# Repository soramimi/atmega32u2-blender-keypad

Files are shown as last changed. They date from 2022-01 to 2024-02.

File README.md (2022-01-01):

# atmega32u2-blender-keypad

Customized keypad for modeling with Blender.

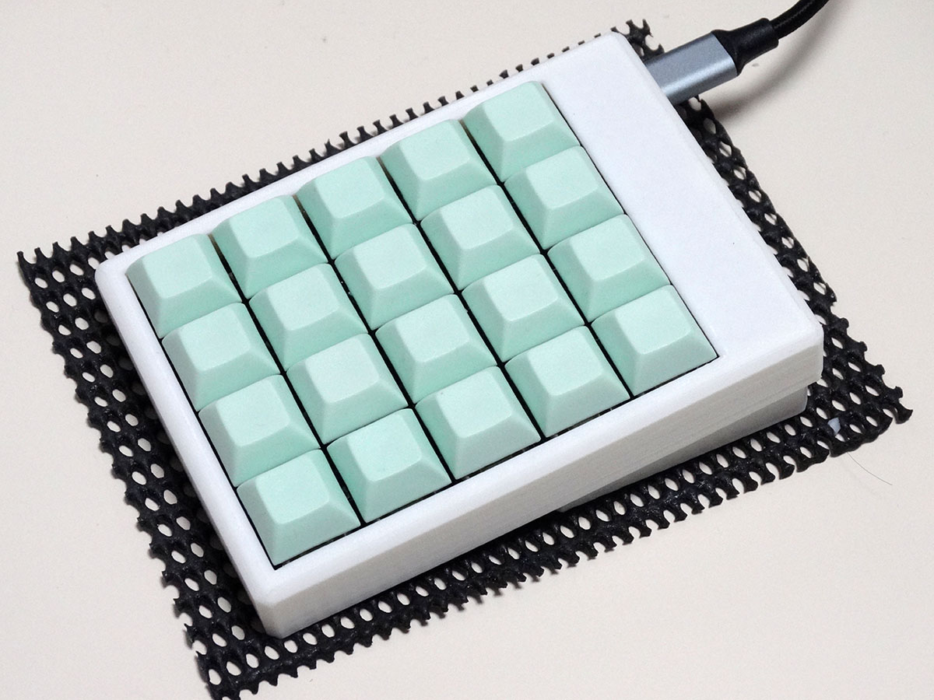
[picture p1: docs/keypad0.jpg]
Keypad

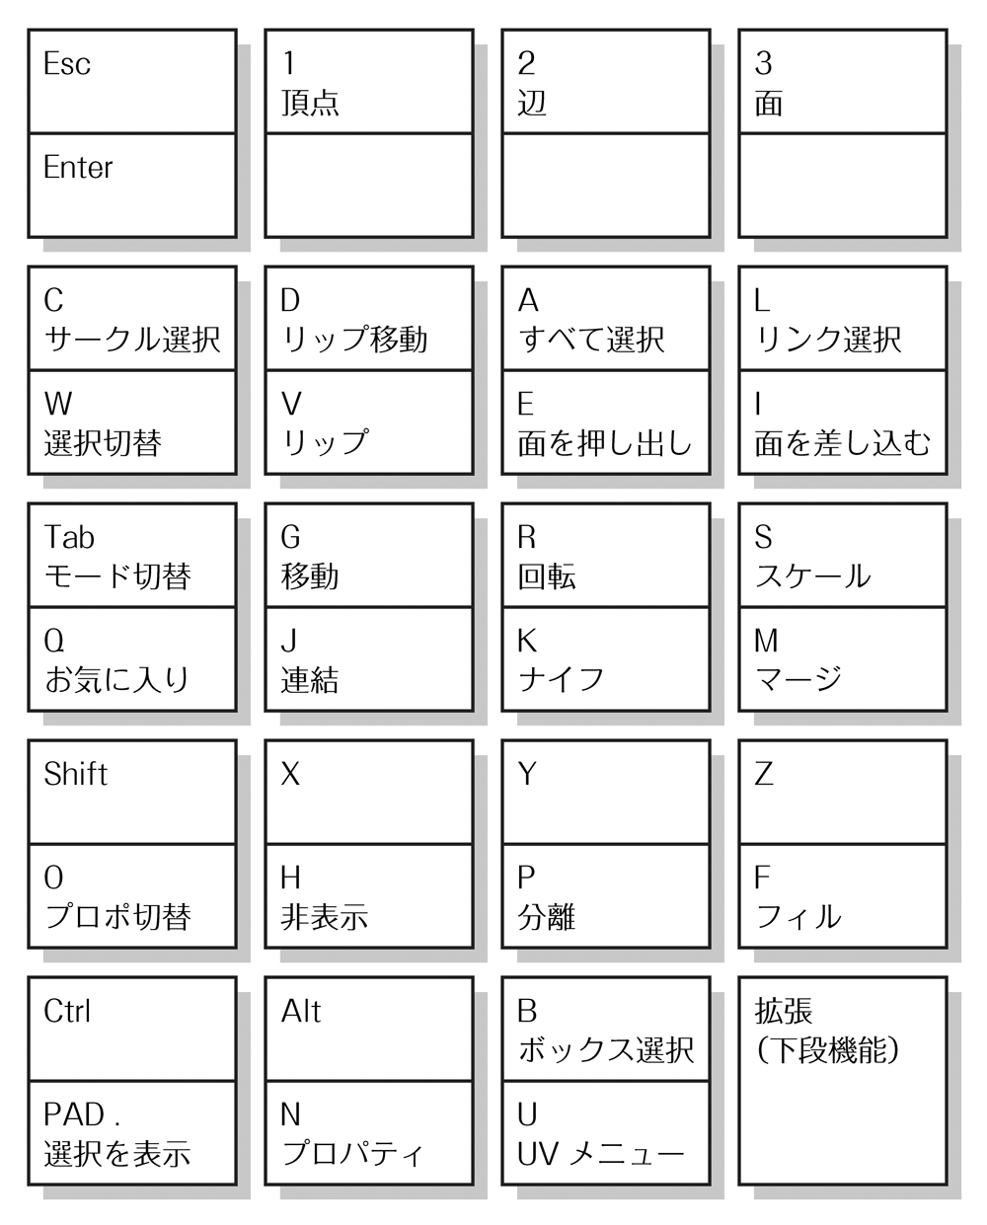
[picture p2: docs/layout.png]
Layout

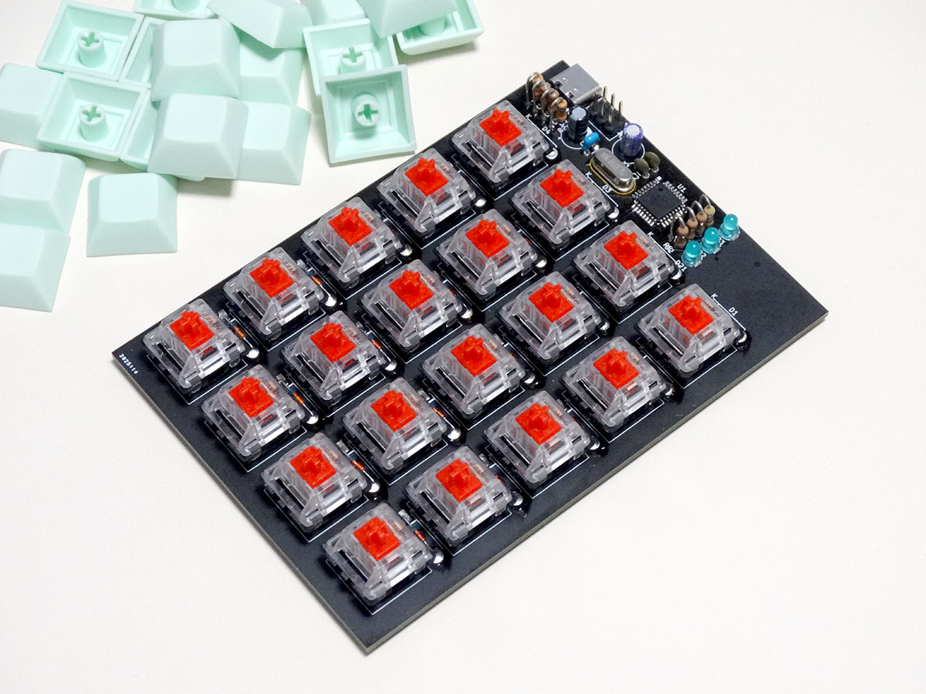
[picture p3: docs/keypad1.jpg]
PCB1

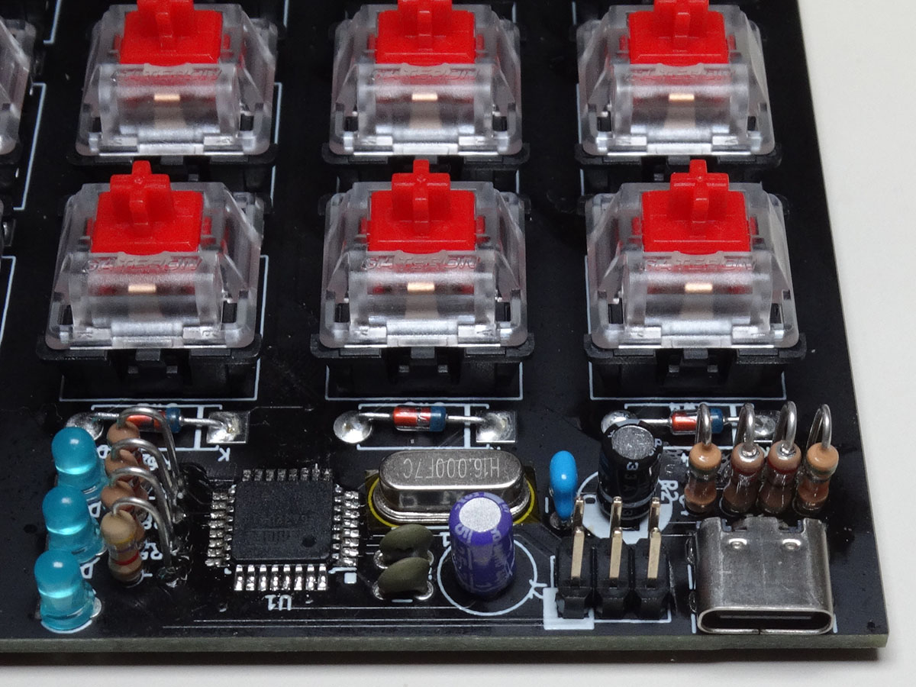
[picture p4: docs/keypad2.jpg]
PCB2


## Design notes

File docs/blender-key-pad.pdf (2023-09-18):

Esc

Enter

W
選択切替

G
移動

S
スケール

K
ナイフ

P
分離

H
非表示

N
サイドバー

J
連結

Q
お気に入り

F
フィル

D
リップ移動

I
面を差し込む

E
面を押し出し

Tab
モード切替

Shift+7
選択面を正面

5
投影法切替

O
プロポ切替

T
ツールバー

U
UV メニュー

M
マージ

R
回転

A
すべて選択

L
リンク選択

C
サークル選択

B
ボックス選択
Shift | X
Ctrl | Alt
選択をズーム

2ｽﾄﾛｰｸ

拡張
（下段機能）
Y | Z

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
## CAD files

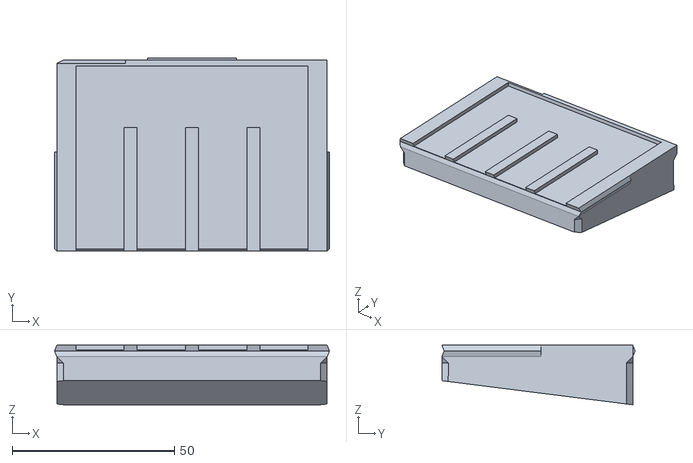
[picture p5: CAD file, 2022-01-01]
case/20keypad-c-bottom-a.stl
84.7 x 59.5 x 18.3

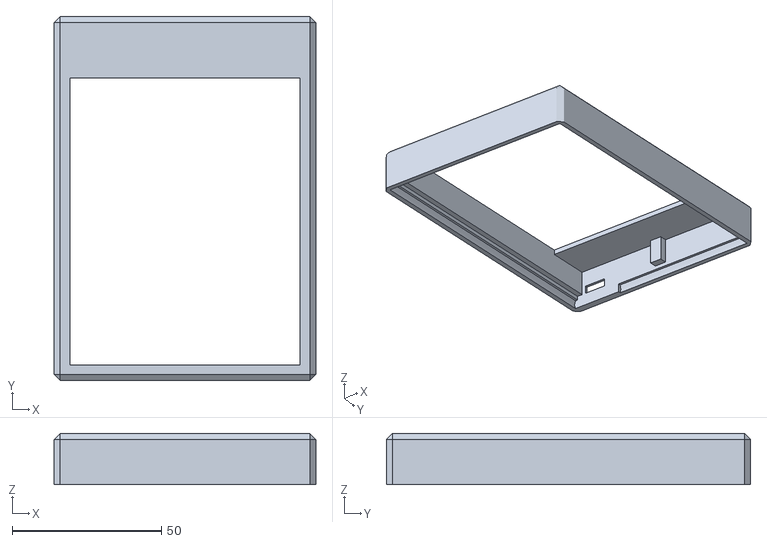
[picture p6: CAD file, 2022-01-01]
case/20keypad-c-cover.stl
87.7 x 122.0 x 17.1

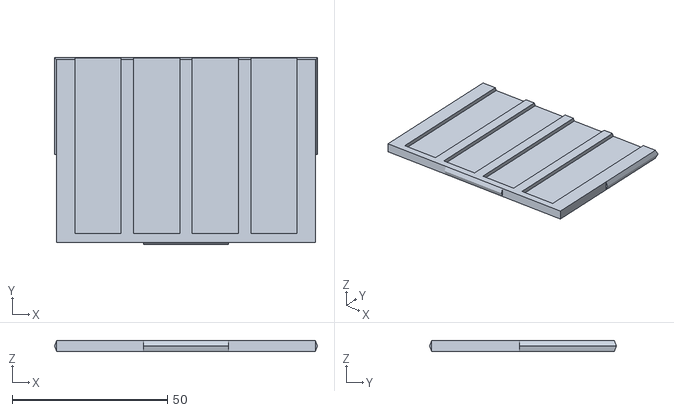
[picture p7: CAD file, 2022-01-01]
case/20keypad-c-bottom-b.stl
84.7 x 60.2 x 3.50

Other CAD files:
case/20keypad-c-bottom-a.blend
case/20keypad-c-bottom-b.blend
case/20keypad-c-cover.blend
case/20keypad-c.blend

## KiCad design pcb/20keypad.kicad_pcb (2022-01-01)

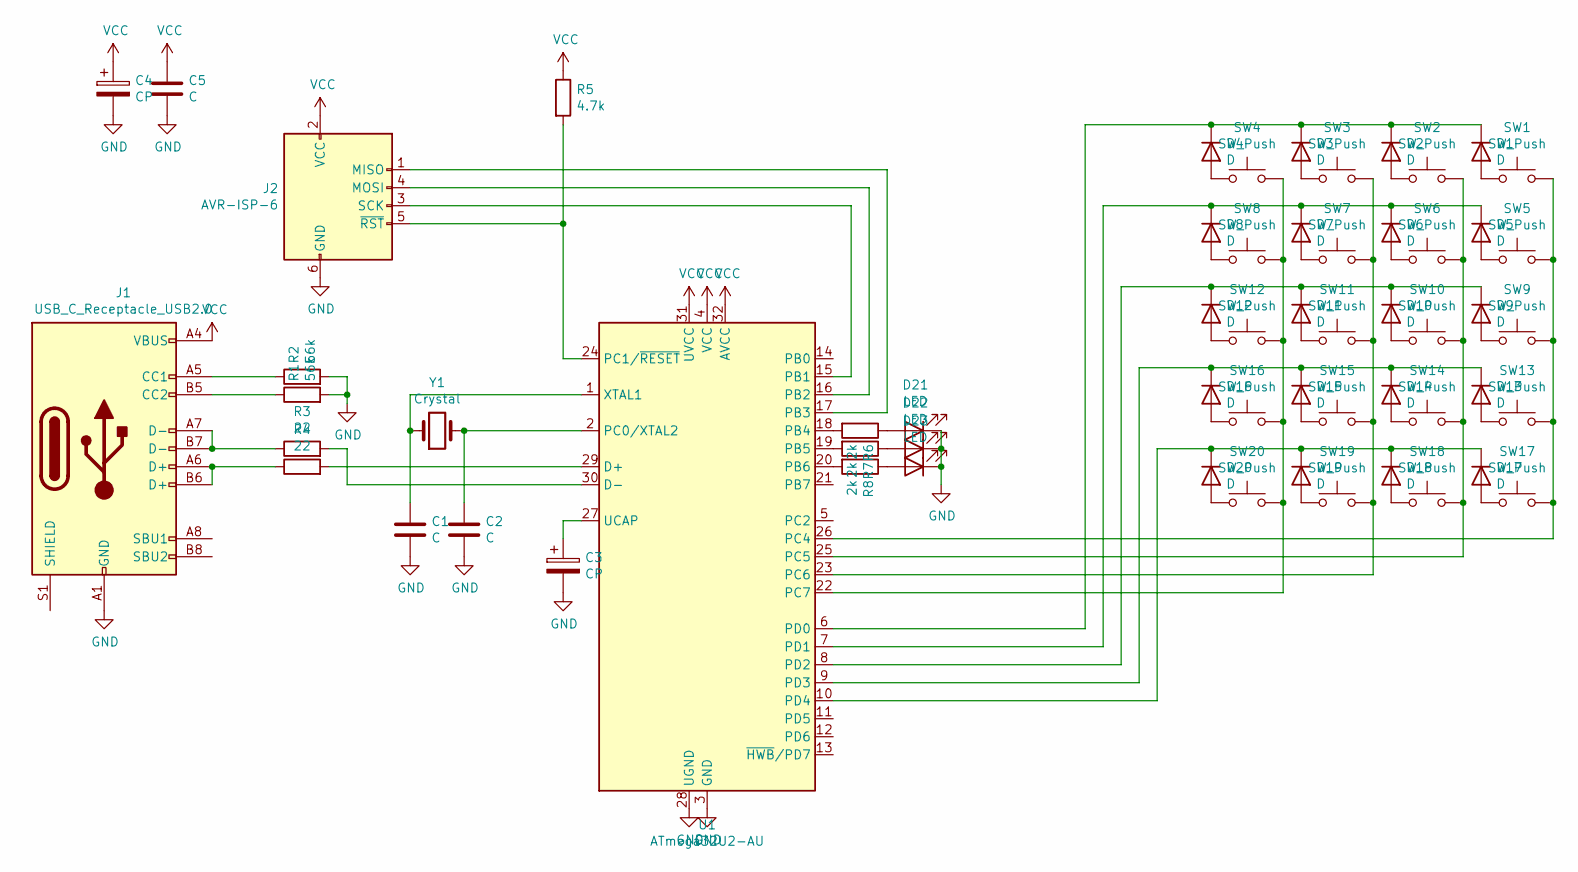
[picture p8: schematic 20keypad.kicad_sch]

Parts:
C1, C2, C5: C; C_Disc_D3.0mm_W1.6mm_P2.50mm
C3, C4: CP; CP_Radial_D6.3mm_P2.50mm
D1, D2, D3, D4, D5, D6, D7, D8, D9, D10, D11, D12, D13, D14, D15, D16, D17, D18, D19, D20: D; D_A-405_P7.62mm_Horizontal
D21, D22, D23: LED; LED_D3.0mm
J1: USB_C_Receptacle_USB2.0; USB_C_Receptacle_HRO_TYPE-C-31-M-12
J2: AVR-ISP-6; PinHeader_2x03_P2.54mm_Vertical
R1, R2: 56k; R_Axial_DIN0204_L3.6mm_D1.6mm_P2.54mm_Vertical
R3, R4: 22; R_Axial_DIN0204_L3.6mm_D1.6mm_P2.54mm_Vertical
R5: 4.7k; R_Axial_DIN0204_L3.6mm_D1.6mm_P2.54mm_Vertical
R6, R7, R8: 2k; R_Axial_DIN0204_L3.6mm_D1.6mm_P2.54mm_Vertical
SW1, SW2, SW3, SW4, SW5, SW6, SW7, SW8, SW9, SW10, SW11, SW12, SW13, SW14, SW15, SW16, SW17, SW18, SW19, SW20: SW_Push; SW_Cherry_MX_1.00u_PCB
U1: ATmega32U2-AU; TQFP-32_7x7mm_P0.8mm
Y1: Crystal; Crystal_HC49-U_Vertical

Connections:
GND: C1.2, C2.2, C3.2, C4.2, C5.2, D21.1 (K), D22.1 (K), D23.1 (K), J1.A1 (GND), J1.A12 (GND), J1.B1 (GND), J1.B12 (GND), J2.6 (GND), R1.2, R2.2, U1.3 (GND), U1.28 (UGND)
unnamed: C1.1, U1.1 (XTAL1), Y1.1
unnamed: C2.1, U1.2 (PC0/XTAL2), Y1.2
unnamed: C3.1, U1.27 (UCAP)
unnamed: D1.1 (K), D2.1 (K), D3.1 (K), D4.1 (K), U1.6 (PD0)
unnamed: D1.2 (A), SW1.1
unnamed: D2.2 (A), SW2.1
unnamed: D3.2 (A), SW3.1
unnamed: D4.2 (A), SW4.1
unnamed: D5.1 (K), D6.1 (K), D7.1 (K), D8.1 (K), U1.7 (PD1)
unnamed: D5.2 (A), SW5.1
unnamed: D6.2 (A), SW6.1
unnamed: D7.2 (A), SW7.1
unnamed: D8.2 (A), SW8.1
unnamed: D9.2 (A), SW9.1
unnamed: D9.1 (K), D10.1 (K), D11.1 (K), D12.1 (K), U1.8 (PD2)
unnamed: D10.2 (A), SW10.1
unnamed: D11.2 (A), SW11.1
unnamed: D12.2 (A), SW12.1
unnamed: D13.1 (K), D14.1 (K), D15.1 (K), D16.1 (K), U1.9 (PD3)
unnamed: D13.2 (A), SW13.1
unnamed: D14.2 (A), SW14.1
unnamed: D15.2 (A), SW15.1
unnamed: D16.2 (A), SW16.1
unnamed: D17.1 (K), D18.1 (K), D19.1 (K), D20.1 (K), U1.10 (PD4)
unnamed: D17.2 (A), SW17.1
unnamed: D18.2 (A), SW18.1
unnamed: D19.2 (A), SW19.1
unnamed: D20.2 (A), SW20.1
unnamed: D21.2 (A), R6.1
unnamed: D22.2 (A), R7.1
unnamed: D23.2 (A), R8.1
unnamed: J1.A5 (CC1), R2.1
unnamed: J1.A6 (D+), J1.B6 (D+), R4.1
unnamed: J1.A7 (D-), J1.B7 (D-), R3.1
unnamed: J1.B5 (CC2), R1.1
unnamed: J2.1 (MISO), U1.17 (PB3)
unnamed: J2.3 (SCK), U1.15 (PB1)
unnamed: J2.4 (MOSI), U1.16 (PB2)
unnamed: J2.5 (~RST), R5.2, U1.24 (PC1/~RESET)
unnamed: R3.2, U1.30 (D-)
unnamed: R4.2, U1.29 (D+)
unnamed: R6.2, U1.18 (PB4)
unnamed: R7.2, U1.19 (PB5)
unnamed: R8.2, U1.20 (PB6)
unnamed: SW1.2, SW5.2, SW9.2, SW13.2, SW17.2, U1.26 (PC4)
unnamed: SW2.2, SW6.2, SW10.2, SW14.2, SW18.2, U1.25 (PC5)
unnamed: SW3.2, SW7.2, SW11.2, SW15.2, SW19.2, U1.23 (PC6)
unnamed: SW4.2, SW8.2, SW12.2, SW16.2, SW20.2, U1.22 (PC7)
VCC: C4.1, C5.1, J1.A4 (VBUS), J1.A9 (VBUS), J1.B4 (VBUS), J1.B9 (VBUS), J2.2 (VCC), R5.1, U1.4 (VCC), U1.31 (UVCC), U1.32 (AVCC)

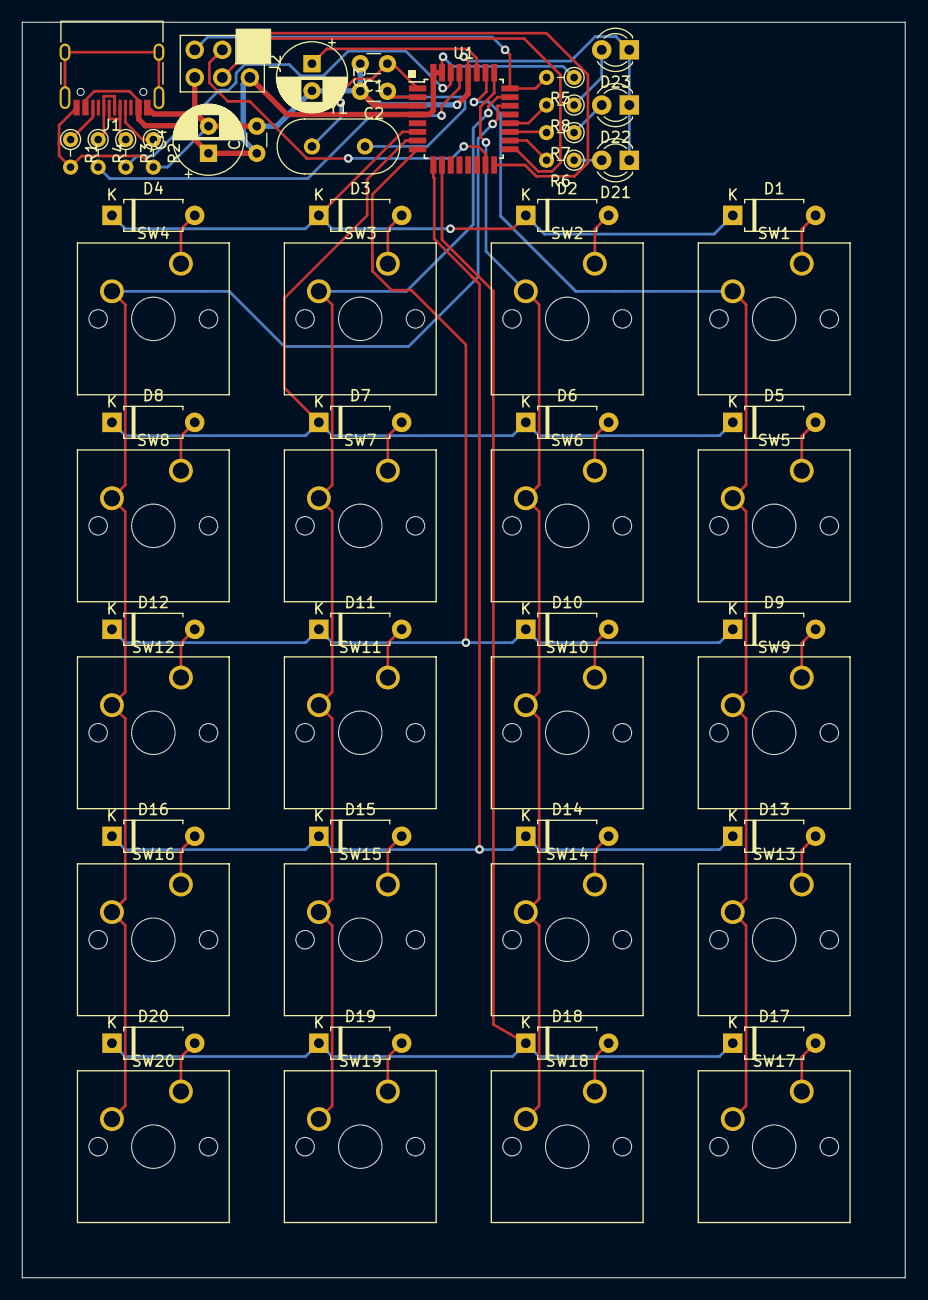
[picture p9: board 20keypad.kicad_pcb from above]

Board: 2 copper layers, 81.3 x 115.6 mm, 60 parts (0 on the bottom side), 50 nets.

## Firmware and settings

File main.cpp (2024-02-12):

#include <string.h>
#include <stdlib.h>
#include <avr/io.h>
#include <avr/pgmspace.h>
#include <avr/interrupt.h>
#include <util/delay.h>
extern "C" {
#include "usb.h"
}

#define SCALE 125
static unsigned short _scale = 0;
static unsigned long _time_s;
static unsigned short _time_ms = 0;
static signed char _blink = 0;
ISR(TIMER0_OVF_vect, ISR_NOBLOCK)
{
	_scale += 16;
	if (_scale >= SCALE) {
		_scale -= SCALE;
		_time_ms++;
		if (_time_ms >= 1000) {
			_time_ms = 0;
			_time_s++;
		}
		if (_blink >= 25) {
			_blink = -25;
		} else {
			_blink++;
		}
	}
}

void led(int n, bool f)
{
	uint8_t mask = 0x40 >> n;
	if (f) {
		PORTB |= mask;
	} else {
		PORTB &= ~mask;
	}
}

extern "C" void debug(int n)
{
	led(0, n & 1);
	led(1, n & 2);
	led(2, n & 4);
}

#if KEYBOARD_ENABLED

#define KEY_MATRIX_ROWS 5
#define KEY_MATRIX_COLS 4

enum {
	MM_CTRL   = 0x01,
	MM_SHIFT  = 0x02,
	MM_ALT    = 0x04,
	MM_EXTRA  = 0x08,
	MM_EXTRA2 = 0x10,
	MM_SINGLESHOT = 0x80
};

static bool key_changed = false;
static int matrix_line = 0;
static uint8_t key_matrix[KEY_MATRIX_ROWS];
static uint8_t modifiers = 0;
static bool extra_modifier_released = false;
static uint8_t layout_set = 0;
static char two_stroke = 0;

// layout set 0

const PROGMEM uint16_t keytable_0a[] = {
	0x29, 0x1e, 0x1f, 0x20,
	0x05, 0x04, 0x07, 0x08,
	0x2b, 0x0a, 0x15, 0x16,
	0x00, 0x1b, 0x1c, 0x1d,
	0x00, 0x00, 0x14, 0x00,
};

const PROGMEM uint16_t keytable_0b[] = {
	0x28, 0x12, 0x17, 0x11,
	0x06, 0x0f, 0x19, 0x0c,
	0x1a, 0x0d, 0x0e, 0x10,
	0x00, 0x0b, 0x13, 0x09,
	0x00, 0x00, 0x18, 0x00,
};

const PROGMEM uint16_t keytable_0t[] = {
	0xff, 0x00, 0x00, 0x00,
	0xff, 0xff, 0xff, 0xff,
	0xff, 0xff, 0xff, 0xff,
	0xff, 0xff, 0xff, 0xff,
	0x63/*pad.*/, 0x5f | ((MM_SINGLESHOT | MM_SHIFT) << 8)/*shift+pad7*/, 0x5d/*pad5*/, 0x00,
};

// layout set 1

const PROGMEM uint16_t keytable_1a[] = {
	0x29, 0x04, 0x0e, 0x10,
	0x2c, 0x0c, 0x16, 0x1c,
	0x00, 0x18, 0x17, 0x15,
	0x00, 0x08, 0x11, 0x1a,
	0x00, 0x12, 0x0b, 0x00,
};

const PROGMEM uint16_t keytable_1b[] = {
	0x28, 0x4c, 0x0a, 0x14,
	0x2b, 0x2a, 0x1d, 0x0d,
	0x00, 0x09, 0x07, 0x0f,
	0x00, 0x1b, 0x06, 0x19,
	0x00, 0x13, 0x05, 0x00,
};

const PROGMEM uint16_t keytable_1c[] = { // MM_EXTRA2
	0x8b, 0x8a, 0x30, 0x32,
	0xff, 0x4a, 0x52, 0x4b,
	0xff, 0x50, 0x2d, 0x4f,
	0xff, 0x4d, 0x51, 0x4e,
	0xff, 0x36, 0x37, 0x00,
};

const PROGMEM uint16_t keytable_1t[] = { // two stroke 1
	0xff, 0x00, 0x00, 0x00,
	0x2f, 0x24, 0x25, 0x26,
	0xff, 0x21, 0x22, 0x23,
	0xff, 0x1e, 0x1f, 0x20,
	0xff, 0x27, 0x37, 0x36,
};

const PROGMEM uint16_t keytable_1u[] = { // two stroke 2
	0xff, 0x00, 0x00, 0x00,
	0xff, 0x8b, 0x8a, 0xff,
	0xff, 0x8b | ((MM_SINGLESHOT | MM_CTRL) << 8), 0x8a | ((MM_SINGLESHOT | MM_CTRL) << 8), 0x35,
	0xff, 0x09 | ((MM_SINGLESHOT | MM_CTRL | MM_SHIFT) << 8), 0x0d | ((MM_SINGLESHOT | MM_CTRL | MM_SHIFT) << 8), 0x88,
	0xff, 0x36, 0x37, 0x00,
};

const PROGMEM uint16_t keytable_1v[] = { // two stroke 3
	0xff, 0x00, 0x00, 0x00,
	0xff, 0x2e, 0x30, 0x32,
	0xff, 0x33, 0x34, 0x2f,
	0xff, 0x38, 0x87, 0x89,
	0xff, 0x36, 0x37, 0x00,
};

// layout set 2

const PROGMEM uint16_t keytable_2a[] = {
	0x29, 0x00, 0x00, 0x00,
	0x3a, 0x3b, 0x3c, 0x3d,
	0x3e, 0x3f, 0x40, 0x41,
	0x42, 0x43, 0x44, 0x45,
	0x00, 0x00, 0x00, 0x00,
};

const PROGMEM uint16_t keytable_2b[] = {
	0x28, 0x00, 0x00, 0x00,
	0x00, 0x00, 0x00, 0x00,
	0x00, 0x00, 0x00, 0x00,
	0x00, 0x00, 0x00, 0x00,
	0x00, 0x00, 0x00, 0x00,
};

//

void set_layout_set(uint8_t mode)
{
	layout_set = mode;
}

bool clear_key(uint8_t key)
{
	bool changed = false;
	if (key > 0) {
		if (key >= 0xe0 && key < 0xe8) {
			uint8_t c = keyboard_data[0];
			uint8_t d = c & ~(1 << (key - 0xe0));
			if (c != d) {
				keyboard_data[0] = d;
				changed = true;
			}
		}
		uint8_t i = 8;
		while (i > 2) {
			i--;
			if (keyboard_data[i] == key) {
				if (i < 7) {
					memmove(keyboard_data + i, keyboard_data + i + 1, 7 - i);
				}
				keyboard_data[7] = 0;
			}
			changed = true;
		}
	}
	return changed;
}

bool press_key(uint8_t key, bool pressed)
{
	bool changed = false;
	if (key > 0 && key < 0xff) { // 0x00 is no key, 0xff is dummy
		if (pressed) {
			if (key >= 0xe0 && key < 0xe8) {
				uint8_t c = keyboard_data[0];
				uint8_t d = c | (1 << (key - 0xe0));
				if (c != d) {
					keyboard_data[0] = d;
					changed = true;
				}
			} else if (key > 0) {
				if (keyboard_data[2] != key) {
					clear_key(key);
					memmove(keyboard_data + 3, keyboard_data + 2, 5);
					keyboard_data[2] = key;
					changed = true;
				}
			}
		} else {
			changed |= clear_key(key);
		}
		keyboard_data[1] = 0;
	}
	return changed;
}

void select_key_matrix_line(int i)
{
	PORTD = ~(0x01 << i);
}

uint8_t read_key_pins()
{
	uint8_t pins = PINC; // read pins
	// shift and invert bits
	pins |= 0x0f;
	pins ^= (pins >> 7) & 0x01;
	pins ^= (pins >> 5) & 0x02;
	pins ^= (pins >> 3) & 0x04;
	pins ^= (pins >> 1) & 0x08;
	return pins & 0x0f;
}

bool scan_key_matrix_line(int row)
{
	static uint16_t current_key_code = 0;
	static uint8_t single_shot_state = 0;

	const bool is_last_row = (row == KEY_MATRIX_ROWS - 1);
	const bool ex = modifiers & MM_EXTRA;

	bool changed = false;

	uint16_t const *keytable = nullptr;
	switch (two_stroke) {
	default:
		switch (layout_set) {
		default:
			keytable = !ex ? keytable_0a : keytable_0b;
			break;
		case 1:
			if (!(modifiers & MM_EXTRA2)) {
				keytable = !ex ? keytable_1a : keytable_1b;
			} else {
				keytable = keytable_1c;
			}
			break;
		case 2:
			keytable = !ex ? keytable_2a : keytable_2b;
			break;
		}
		break;
	case 1:
		switch (layout_set) {
		default:
			keytable = keytable_0t;
			break;
		case 1:
			keytable = keytable_1t;
			break;
		case 2:
			break;
		}
		break;
	case 2:
		switch (layout_set) {
		default:
			break;
		case 1:
			keytable = keytable_1u;
			break;
		case 2:
			break;
		}
		break;
	case 3:
		switch (layout_set) {
		default:
			break;
		case 1:
			keytable = keytable_1v;
			break;
		case 2:
			break;
		}
		break;
	}

	if (single_shot_state == 8) { // シングルショット送信済み
#if 0 // シングルショットを無効にする場合
		single_shot_state = !ex ? 0 : 2; // シングルショット処理済み
		two_stroke = false;
#else // シングルショットを継続する場合
		single_shot_state = 2;
#endif
		press_key((uint8_t)current_key_code, false); // シングルショット開放
		current_key_code = 0;
		changed = true;
	} else {
		uint8_t bits = 0;
		for (int r = 0; r < KEY_MATRIX_ROWS; r++) {
			bits |= key_matrix[r];
		}
		if (bits == 0) { // すべてのキーが離された
			single_shot_state = 0;
			current_key_code = 0;
		}
	}

	uint8_t prev_pins = key_matrix[row];
	uint8_t curr_pins = read_key_pins();

	for (int col = 0; col < KEY_MATRIX_COLS; col++) {
		int i = 4 * row + col;
		uint16_t c = 0;
		if (keytable) {
			c = pgm_read_word(keytable + i);
		}
		bool curr = (curr_pins >> col) & 1;
		bool prev = (prev_pins >> col) & 1;
		if (curr) {
			if (!prev) { // 押された
				if (two_stroke != 0) {
					switch (i) {
					case 1:
					case 2:
					case 3:
						set_layout_set(i - 1);
						continue;
					default:
						if (c == 0) {
							two_stroke = 0;
						} else {
							if (layout_set == 0) {
								current_key_code = c;
								single_shot_state = 6; // シングルショット送信待ち（離されたときにキーが送信される）
								continue;
							}
						}
						break;
					}
				}
				if (c & (MM_SINGLESHOT << 8)) {
					current_key_code = c;
					single_shot_state = 6;
					continue;
				}
				bool normal = true;
				switch (i) {
				case 4 * 2 + 0:
					if (ex && two_stroke == 0) {
						if (layout_set == 1) {
							two_stroke = 3;
							continue;
						}
					}
					break;
				case 4 * 3 + 0:
					if (ex && two_stroke == 0) {
						two_stroke = 2;
						continue;
					}
					break;
				case 4 * 4 + 0:
					if (ex && two_stroke == 0) {
						two_stroke = 1;
						continue;
					}
					break;
				case 4 * 4 + 3:
					if (layout_set == 1) {
						if (key_matrix[4] & 0x01) {
							two_stroke = 1;
							continue;
						}
						if (key_matrix[3] & 0x01) {
							two_stroke = 2;
							continue;
						}
						if (key_matrix[2] & 0x01) {
							if (layout_set == 1) {
								two_stroke = 3;
								continue;
							}
						}
					}
					single_shot_state |= 2; // シングルショット押下待ち
					continue;
				}
				if (normal) {
					if (c != 0) { // 通常のキー押下
						press_key((uint8_t)current_key_code, false);
						press_key(c, true);
						current_key_code = c;
						changed = true;
					}
					single_shot_state = 1; // シングルショット無効
				} else if (c != 0) {
					if (single_shot_state == 0 || single_shot_state == 2) {
						if (current_key_code != c) {
							current_key_code = c;
							single_shot_state |= 4; // シングルショット送信待ち
						} else {
							single_shot_state = 1; // シングルショット無効
						}
					}
				}
			}
		} else {
			if (prev) { // 離された
				if (single_shot_state == 6) { // シングルショット送信待ち状態？
					single_shot_state = 7; // シングルショット送信予約
				} else { // 通常のキー開放
					press_key((uint8_t)current_key_code, false);
					changed = true;
				}
			}
		}
	}

	key_matrix[row] = curr_pins;

	if (is_last_row) {
		modifiers = 0;

		if (single_shot_state == 6) { // シングルショット送信予約状態？
			modifiers = current_key_code >> 8;
			single_shot_state = 7; // シングルショット送信予約状態
		} else if (single_shot_state == 7) { // シングルショット送信予約状態？
			modifiers = current_key_code >> 8;
			press_key((uint8_t)current_key_code, true);
			single_shot_state = 8; // シングルショット送信済み
			changed = true;
		} else {
			auto SETMODIFIER = [&](bool f, uint8_t bit){
				if (f && bit) {
					modifiers |= bit;
				} else {
					modifiers &= ~bit;
				}
			};
			SETMODIFIER(key_matrix[4] & 0x01, MM_CTRL);
			if (layout_set == 0) {
				SETMODIFIER(key_matrix[3] & 0x01, MM_SHIFT);
				SETMODIFIER(key_matrix[4] & 0x02, MM_ALT);
			} else if (layout_set == 1) {
				SETMODIFIER(key_matrix[3] & 0x01, MM_SHIFT);
				SETMODIFIER(key_matrix[2] & 0x01, MM_EXTRA2);
			} else if (layout_set == 2) {
				SETMODIFIER(key_matrix[4] & 0x02, MM_SHIFT);
				SETMODIFIER(key_matrix[4] & 0x04, MM_ALT);
			}

			if (key_matrix[4] & 0x08) {
				modifiers |= MM_EXTRA;
			} else {
				if (modifiers & MM_EXTRA) {
					// when the extra modifier released, release other modifier keys
					extra_modifier_released = true;
					changed = true;
				}
				modifiers &= ~MM_EXTRA;
				two_stroke = 0;
				if (single_shot_state != 8) {
					single_shot_state = 0;
				}
			}
		}

		changed |= press_key(0xe0, modifiers & MM_CTRL); // ctrl
		changed |= press_key(0xe1, modifiers & MM_SHIFT); // shift
		changed |= press_key(0xe2, modifiers & MM_ALT); // alt
	}

	return changed;
}
#endif

int main()
{
	static unsigned short time_ms = 0;

	memset(key_matrix, 0, KEY_MATRIX_ROWS);

	// 16 MHz clock
	CLKPR = 0x80;
	CLKPR = 0;
	// Disable JTAG
	MCUCR |= 0x80;
	MCUCR |= 0x80;

	_delay_ms(10);

	PORTB = 0x00;
	DDRB = 0x70; // LEDs

	PORTC = 0xff; // pull-up
	DDRC = 0x00;

	PORTD = 0xff;
	DDRD = 0x1f;

	TCCR0B = 0x02; // 1/8 prescaling
	TIMSK0 |= 1 << TOIE0;

	usb_init();
	while (!usb_configured()) {
		_delay_ms(10);
	}

	sei();  // enable interrupts

#if KEYBOARD_ENABLED
	select_key_matrix_line(matrix_line);
#endif

	set_layout_set(0);

	while (1) {
		_delay_us(1);
		bool send_ready = false;
		if (time_ms != _time_ms) {
			time_ms = _time_ms;
			if (time_ms & 1) { // every 2ms
				send_ready = true;
#if KEYBOARD_ENABLED
				if (matrix_line < KEY_MATRIX_ROWS) {
					if (scan_key_matrix_line(matrix_line)) { // scan
						key_changed = true;
					}
					matrix_line++;
				}
				if (matrix_line == KEY_MATRIX_ROWS) {
					if (key_changed && send_ready) {
						send_ready = false;
						key_changed = false;
						const int N = sizeof(keyboard_data);
						uint8_t data[N];
						memcpy(data, keyboard_data, N);
						if (extra_modifier_released) {
							extra_modifier_released = false;
							data[0] = 0; // release modifiers
						}
						usb_keyboard_send(data);
					}
					matrix_line = 0;
				}
				select_key_matrix_line(matrix_line); // select line to next scan
#endif
			}
		}

		if (send_ready) {
			send_ready = false;

#if MOUSE_ENABLED
			mouse_data[0] = 0;
			mouse_data[1] = 1;
			mouse_data[2] = 1;
			mouse_data[3] = 0;
			usb_mouse_send();
#endif
		}

		bool on = true;
		if (two_stroke != 0) {
			on = _blink > 0; // 点滅
		}
		led(0, on && layout_set == 0);
		led(1, on && layout_set == 1);
		led(2, on && layout_set == 2);
	}
}

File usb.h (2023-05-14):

#ifndef USB_H
#define USB_H

#include <stdint.h>

#define KEYBOARD_ENABLED 1
#define MOUSE_ENABLED 0

#ifdef __cplusplus
extern "C" {
#endif

void usb_init();			// initialize everything
uint8_t usb_configured();		// is the USB port configured
void usb_remote_wakeup();

#if KEYBOARD_ENABLED
int8_t usb_keyboard_send(uint8_t const *data);
extern uint8_t keyboard_data[8];
extern volatile uint8_t keyboard_leds;
#endif

#if MOUSE_ENABLED
int8_t usb_mouse_send();
extern uint8_t mouse_data[4];
#endif

#ifdef __cplusplus
}
#endif

#include <avr/io.h>
#include <avr/pgmspace.h>
#include <avr/interrupt.h>

#define EP_TYPE_CONTROL 0x00
#define EP_TYPE_BULK_IN 0x81
#define EP_TYPE_BULK_OUT 0x80
#define EP_TYPE_INTERRUPT_IN 0xc1
#define EP_TYPE_INTERRUPT_OUT 0xc0
#define EP_TYPE_ISOCHRONOUS_IN 0x41
#define EP_TYPE_ISOCHRONOUS_OUT 0x40

#define EP_SINGLE_BUFFER 0x02
#define EP_DOUBLE_BUFFER 0x06

#define EP_SIZE(s) ((s) == 64 ? 0x30 : ((s) == 32 ? 0x20 : ((s) == 16 ? 0x10 : 0x00)))

#define MAX_ENDPOINT 4

#define LSB(n) (n & 255)
#define MSB(n) ((n >> 8) & 255)

// ATmega32u2
#if defined(__AVR_ATmega32U2__)
#define HW_CONFIG()  (REGCR = 0x00)
#define PLL_CONFIG() (PLLCSR = 0x06)      //controls USB interface clock 0x06 for 16MHz clock source 0x02 for 8MHz clock source
#define USB_CONFIG() (USBCON = (1<<USBE)) //no OPGPADE for the ATmega32u2
#define USB_FREEZE() (USBCON = ((1<<USBE)|(1<<FRZCLK)))
// ATmega32u4, Teensy 2.0 
#elif defined(__AVR_ATmega32U4__)
#define HW_CONFIG() (UHWCON = 0x01)
#define PLL_CONFIG() (PLLCSR = 0x12)
#define USB_CONFIG() (USBCON = ((1<<USBE)|(1<<OTGPADE)))
#define USB_FREEZE() (USBCON = ((1<<USBE)|(1<<FRZCLK)))
// AT90USB162, Teensy 1.0
#elif defined(__AVR_AT90USB162__)
#define HW_CONFIG()
#define PLL_CONFIG() (PLLCSR = ((1<<PLLE)|(1<<PLLP0)))
#define USB_CONFIG() (USBCON = (1<<USBE))
#define USB_FREEZE() (USBCON = ((1<<USBE)|(1<<FRZCLK)))
// AT90USB646, Teensy++ 1.0
#elif defined(__AVR_AT90USB646__)
#define HW_CONFIG() (UHWCON = 0x81)
#define PLL_CONFIG() (PLLCSR = 0x1A)
#define USB_CONFIG() (USBCON = ((1<<USBE)|(1<<OTGPADE)))
#define USB_FREEZE() (USBCON = ((1<<USBE)|(1<<FRZCLK)))
// AT90USB1286, Teensy++ 2.0 
#elif defined(__AVR_AT90USB1286__)
#define HW_CONFIG() (UHWCON = 0x81)
#define PLL_CONFIG() (PLLCSR = 0x16)
#define USB_CONFIG() (USBCON = ((1<<USBE)|(1<<OTGPADE)))
#define USB_FREEZE() (USBCON = ((1<<USBE)|(1<<FRZCLK)))
#endif

// standard control endpoint request types
#define GET_STATUS 0
#define CLEAR_FEATURE 1
#define SET_FEATURE 3
#define SET_ADDRESS 5
#define GET_DESCRIPTOR 6
#define GET_CONFIGURATION 8
#define SET_CONFIGURATION 9
#define GET_INTERFACE 10
#define SET_INTERFACE 11
// HID (human interface device)
#define HID_GET_REPORT 1
#define HID_GET_IDLE 2
#define HID_GET_PROTOCOL 3
#define HID_SET_REPORT 9
#define HID_SET_IDLE 10
#define HID_SET_PROTOCOL 11
// CDC (communication class device)
#define CDC_SET_LINE_CODING 0x20
#define CDC_GET_LINE_CODING 0x21
#define CDC_SET_CONTROL_LINE_STATE 0x22
#endif

//#endif

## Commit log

2022-01-01 fix typo
    [20keypad-B_Cu.gbl, 20keypad-B_Mask.gbs, 20keypad-B_Paste.gbp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]
2022-01-01 add case models
    [20keypad-c-bottom-a.blend, 20keypad-c-bottom-a.stl, 20keypad-c-bottom-b.blend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]
